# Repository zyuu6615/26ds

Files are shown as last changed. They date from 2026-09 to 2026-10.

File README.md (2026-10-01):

# 车载平衡滚球运动控制系统

> 2026 年全国大学生电子设计竞赛（TI 杯）赛区赛暨模拟电子系统设计专题赛选拔赛
> **H 题 · 省一等奖**

一辆四轮小车沿黑线循迹行驶，同时用一根舵机驱动的摆杆把钢珠稳定在指定位置。

```
MaixCAM2（NPU 视觉）──UART 115200──► STM32F407（控制）──► 舵机 / 双电机
     识别钢珠位置                     球杆闭环 + 循迹 + 显示
```

## 仓库结构

| 目录 | 内容 |
| :--- | :--- |
| [`01_firmware_stm32/`](01_firmware_stm32/) | 主控固件：循迹、双电机串级 PID、舵机、LCD、视觉串口 |
| [`02_vision_maixcam2/`](02_vision_maixcam2/) | MaixCAM2 视觉：NPU YOLO26 检测钢珠 + 多级容错跟踪 |
| [`03_mechanical_3d/`](03_mechanical_3d/) | 整车与摆杆机构 3D 模型（SolidWorks + 可打印 STEP） |
| [`04_dataset_tools/`](04_dataset_tools/) | 训练数据制作（视频抽帧）与标注格式说明 |

各模块的构建方式、参数含义与设计说明见各自的 README。

## 赛题任务

| 科目 | 要求 |
| :--- | :--- |
| 任务一 | 舵机在安全行程内往复摆动，车不动 |
| 任务二 | 从 A 点顺时针循线一圈停回 A 点，≤20s，停车偏差 ≤2cm |
| 任务三 | 车静止，把钢珠从中心 O 送到 +5cm 再折返 −5cm |
| 任务四 | 带球顺时针通过 B 点，≤8s |
| 任务五 | 球置中心 O，整圈通过 A，≤30s |
| 任务六 | 球置于摆杆任意指定位置并稳定在该位置附近 |

六科目全部实现。控制参数见 `01_firmware_stm32/applications/task.h`。

## 致谢

方案调研阶段参考了 H 题相关的开源实现
感谢运用到的第三方组件以及利用的其他开源方案，万分感谢！！
## 许可

原创代码以 MIT 协议开源，见 [LICENSE](LICENSE)。
`01_firmware_stm32/lcd_driver/` 内含第三方字模数据，版权归原作者；
SolidWorks 标准件参考模型仅供学习交流。

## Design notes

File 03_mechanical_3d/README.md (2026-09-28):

# 03 · 机械结构 3D 模型

车载平衡滚球小车的完整机械设计：底盘、车架、舵机支架、摆杆机构、视觉支架。
全部为自主建模

- **CAD**：SolidWorks（`*.SLDPRT` 零件 / `*.SLDASM` 装配体）
- **交换格式**：`printables_step/` 下 9 个 `*.STEP`，可直接切片打印

## 目录

```
26电赛.SLDASM              总装配体（从这个文件开始看）
*.SLDPRT                   18 个零件
printables_step/           9 个可打印 STEP
```

## 零件清单

### 结构件

| 文件 | 说明 |
| :--- | :--- |
| `大底盘.SLDPRT` | 主底盘，承载全部电子件与机构 ✅STEP |
| `下车架.SLDPRT` | 下层车架，承载电机与轮组 ✅STEP |
| `5CM架台.SLDPRT` | 抬高摆杆支点 ✅STEP |
| `视觉支架.SLDPRT` | 固定 MaixCAM2 ✅STEP |
| `挡板.SLDPRT` | 遮挡/限位 |

### 摆杆机构

| 文件 | 说明 |
| :--- | :--- |
| `水管.SLDPRT` | 摆杆（钢珠滚动导轨） |
| `摆杆撑杆.SLDPRT` | 摆杆撑杆 ✅STEP |
| `摆杆支撑转轴座.SLDPRT` | 转动支点 ✅STEP |
| `摆杆转轴侧固定座.SLDPRT` | 转轴侧向定位 |
| `舵盘摆臂杆.SLDPRT` | 舵机旋转 → 摆杆俯仰 ✅STEP |

### 舵机与连接件

| 文件 | 说明 |
| :--- | :--- |
| `舵机支架.SLDPRT` | 固定舵机本体 |
| `舵机固定脚.SLDPRT` | 舵机安装脚 ✅STEP |
| `连接件.SLDPRT` | 通用连接结构 ✅STEP |
| `合页.SLDPRT` / `合页2.SLDPRT` | 铰链结构 |
| `10kg高速舵机.SLDPRT` | 舵机参考体，非打印件 |
| `25T 塑料舵盘.SLDPRT` | 舵盘参考体，非打印件 |

> ✅STEP 表示该件在 `printables_step/` 下有对应导出。

## 机构要点

舵机旋转经 `舵盘摆臂杆` → `摆杆撑杆` 转成摆杆俯仰。舵机脉宽与倾角近似线性
（500–2500us 对应 0–180°），主控侧水平点标定值为 `1588us`。

撑杆高度会放大同样的舵机转动量对应的倾角变化，等效于改变整个位置环的增益，
**换机构必须重新整定 PID**。

视觉支架的安装角度需保证摆杆在画面中接近水平，否则 `AXIS_*_PX` 要重新标定。

## 使用

1. **看装配**：SolidWorks 打开 `26电赛.SLDASM`，若提示找不到零件，
   把所有文件放同一目录再打开。
2. **直接打印**：用 `printables_step/` 里的 STEP 导入切片软件即可，
   无需 SolidWorks（Fusion / FreeCAD / PrusaSlicer 都能读）。

> 打印参数（层高、填充率、材料、支撑）当时未记录。一般建议承力件用较高填充率，
> 转轴座与撑杆的配合面注意层纹方向以获得更好的抗弯强度。

## 注意

`10kg高速舵机.SLDPRT` 与 `25T 塑料舵盘.SLDPRT` 是外购标准件的参考模型，
用于装配干涉检查，不是打印件，版权归原厂商。

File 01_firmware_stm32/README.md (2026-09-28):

# 01 · STM32F407 主控固件

平衡滚球系统的主控。负责循迹、双电机闭环、舵机摆杆控制、LCD 显示，
以及接收 MaixCAM2 的钢珠坐标并做球杆闭环。

- **MCU**：STM32F407ZGT6
- **构建**：CMake ≥ 3.22 + Ninja + `arm-none-eabi-gcc`
- **调试**：OpenOCD + Cortex-Debug

## 目录

```
applications/          应用层，业务代码都在这里
  app.c/.h             调度入口：10ms 内环 / 20ms 外环 / 显示
  task.c/.h            六个赛题科目的状态机与参数
  tracking.c/.h        循迹外环：灰度质心 -> 转向 PID -> 差速
  pid.c/.h             位置式 PID（微分先行 + 积分限幅）
  motor.c/.h           TB6612FNG 双路电机驱动
  encoder.c/.h         TIM1/TIM3 正交编码器，软件补 16->32 位回绕
  grayscale.c/.h       I2C 8 路灰度传感器
  servo.c/.h           舵机 PWM 驱动 + 往复自检演示
  vision.c/.h          UART4 视觉协议接收
  ball.c/.h            钢球位置环 PD + 加速度前馈
  key.c/.h             4 路按键消抖与边沿检测
  ball_notes.md        球杆闭环调参实测记录
Core/                  CubeMX 生成的 HAL 初始化与中断
Drivers/               CMSIS + STM32F4xx HAL（ST 官方，未改动）
cmake/                 工具链文件与源码列表
lcd_driver/            SPI LCD 驱动 + GB2312 全字库（见下方编码说明）
tools/gen_gb2312_font.py   字库生成脚本
openocd.cfg            下载器配置
STM32F407XX_FLASH.ld   链接脚本
```

## 调度层次

| 周期 | 任务 |
| :--- | :--- |
| 10ms | `Key_Scan()`、速度内环（编码器 → 速度 PID → PWM） |
| 20ms | `Track_Update()` 循迹外环、`Task_Update()` 任务调度、`Ball_Update()` 球杆闭环 |

内环周期必须快于外环，两者由 `APP_OUTER_EVERY` 关联，改一处不会漏另一处。

## 引脚分配

| 功能 | 引脚 | 复用 |
| :--- | :--- | :--- |
| 左/右电机 PWM | PC6 / PC7 | TIM8_CH1 / CH2（20kHz） |
| 左/右电机方向 | PF0/PF1、PF2/PF3 | GPIO |
| 驱动使能 STBY | PF4 | GPIO |
| 左编码器 | PB4 / PA7 | TIM3_CH1 / CH2（AF2） |
| 右编码器 | PE9 / PE11 | TIM1_CH1 / CH2（AF1） |
| 灰度传感器 | PB8 / PB9 | I2C1（地址 0x4C） |
| 舵机 | PD15 | TIM4_CH4（50Hz，500–2500us） |
| 视觉串口 | PA0 / PA1 | UART4（115200 8N1） |
| 按键 | PC2 / PC0 / PF9 / PF7 | KEY1–KEY4 |

## 视觉协议

```
$BALL,<valid>,<x_cm>,<vx_pixel_s>,<confidence>,<frame_time_ms>[,<touch_cm>]*\n
```

`vision.c` 用 UART4 中断 + 512B 环形缓冲接收，单帧上限 64B，
超过 `VISION_TIMEOUT_MS`(200ms) 无有效帧则判定断链。

## 构建

```bash
cmake --preset Debug
cmake --build --preset Debug
```

或用 VS Code 任务 `OpenOCD: flash`。依赖 `arm-none-eabi-gcc`、CMake ≥ 3.22、Ninja、OpenOCD。

`CMakeLists.txt` 里的 `-u _printf_float` 不可删除，`LCD_DisplayDecimals()` 依赖它。

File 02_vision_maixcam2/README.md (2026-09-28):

# 02 · MaixCAM2 视觉模块

平衡滚球系统的视觉前端。在 MaixCAM2 上用 NPU 检测钢珠，换算成摆杆轴线上的
厘米位置，通过串口发给 STM32 主控。

**只负责识别与上报，不参与运动控制。**

- **平台**：MaixCAM2（AX 系列 SoC，带 NPU）
- **框架**：MaixPy
- **模型**：YOLO26 单类检测（`ball`），640×160 输入
- **通信**：UART `/dev/ttyS4` @ 115200 8N1

## 文件

| 文件 | 作用 |
| :--- | :--- |
| [`main.py`](main.py) | 主程序：采集、推理、轴线标定、触摸交互、串口上报、屏幕叠加 |
| [`hybrid_tracker.py`](hybrid_tracker.py) | `HybridBallTracker` —— 多级容错跟踪 |
| [`ball_position.py`](ball_position.py) | 像素 → 物理量换算与自适应 α-β 滤波 |
| [`app.yaml`](app.yaml) | MaixPy 应用打包描述 |
| `models/` | 模型描述文件（`*.mud`）。权重 `*.axmodel` 未入库 |

代码本身注释极简，阈值与标定值都维护在本文档的参数表里。

## 处理流程

```
相机帧 → NPU YOLO26 → 候选筛选 → [丢失时] 多级降级跟踪
                                        │
        像素坐标 → 正交投影到标定轴 → 比例 → cm
                                        │
        自适应 α-β 滤波 → 串口 $BALL → STM32
```

正常帧只跑 YOLO。丢框时按代价从低到高降级：
局部模板匹配 → CLAHE 亮度增强后重检 → 低频全画面模板重定位。
未采用全图 Hough 与 FFT，边缘算力不足。

### 滤波（`ball_position.py`）

| 参数 | 值 |
| :--- | :--- |
| α（静止 → 快动） | `0.20 → 0.95` |
| β | `0.01 → 0.12` |
| `dt` 钳位 | `[5ms, 100ms]` |
| 重置超时 | `250ms` |
| 速度平滑 | `0.65 / 0.35` |

## 串口协议

```
$BALL,<valid>,<x_cm>,<vx_pixel_s>,<confidence>,<frame_time_ms>[,<touch_cm>]*\n
```

`frame_time_ms` 是视觉模块自己的时间戳，只能用于判断视觉端是否卡帧，
不可与 STM32 的 `HAL_GetTick()` 做差。`touch_cm` 是触摸屏指定的目标位置。
主控侧解析见 [`../01_firmware_stm32/applications/vision.c`](../01_firmware_stm32/applications/vision.c)。

## 模型权重

`models/` 下只保留了可读的 `.mud` 描述文件，权重 `*.axmodel`（约 2.6MB/个）未入库。

自行复现：用 [`../04_dataset_tools/`](../04_dataset_tools/) 抽帧 → 标注单类 `ball`
→ 训练 YOLO26 → 转成 AX 系列 NPU 格式 → 连同 `.mud` 放进 `models/<name>/`
→ 更新 `main.py` 里的 `MODEL_PATH`，**并重新标定 `AXIS_*` 四个值**。

## 运行

把 3 个 `.py`、`app.yaml` 与 `models/` 一起按 MaixPy 应用打包后推送到设备。
调试开关都在 `main.py` 顶部（`DEBUG_LOG` / `DRAW_DEBUG` / `SHOW_FPS` /
`USE_WEBRTC` / `PRINT_PROTOCOL` / `TOUCH_*` / `LENS_CORR_*`）。

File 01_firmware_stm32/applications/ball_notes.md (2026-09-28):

# 球杆闭环 —— 实测记录与踩过的坑

重写 `ball.c` / `ball.h` 前把旧版本里【实测得来、不能靠推导重新得到】的信息
留在这里。旧的完整实现（含增益调度、静摩擦补偿、摩擦前馈等全套机制）在
git 提交 `42467a3` 及之前，需要时可以取回。

> ## ⚠ 关于历史参数的一条前提
>
> `b418f9d`（提交信息"快速稳定定点"，Kp=45 / Ki=5 / Kd=68 / 限幅 500 / 全机制开）
> 跑在 **`SERVO_LEVEL_US = 1640`** 上。`42467a3`（"失败"）水平点**仍是 1640**，
> 只是把增益退了回来。**1757 是在那之后才改出来的**，只在纯 PD 的反推实验里
> 验证过左右对称性，从来没有跑过一个真正收敛的闭环。
>
> 所以 **b418f9d 那套参数不能直接抄到 1757 上**：1640 偏了约 117us，它的静摩擦
> 补偿（预载 100 / 天花板 320）有相当一部分实际是在补这个水平点偏差，
> 换到 1757 之后整套配比都不再成立。

## 当前进度

- **阶段一 · 纯 PD** —— 已实现（`ball.c` 控制律段）。Kp=25 / Ki=0 / Kd=45 / 限幅 300，
  其余机制全部未加回。**验收标准：球不来回摆。** 停在离目标一段距离处不动是
  预期结果，不是故障。
  - 第一次实测：**不振荡（阻尼够，Kd 不用动）**，但两个停止点是 17.5 和 20~22，
    **全在目标同一侧** → 水平点偏高约 169us，目标点根本不是平衡点。
  - 处理：`SERVO_LEVEL_US` 1757 → **1588**（推导见 servo.h 第四轮）。待复测。
- 阶段二及以后：见第五节。

> ### 一条新学到的判据
>
> **两个停止点落在目标的同一侧 = 水平点偏了，且偏移量大于起步门槛。**
> 一正一负把目标夹在中间，才说明只剩噪声、可以停止迭代。
> 前三轮之所以误判"已经在噪声里打转"，就是因为当时确实是夹住的 ——
> 方法没错，错在把一次姿态下的结果当成了常数。**姿态一变就得重跑这三行。**

---

## 一、对象模型

球在管子上滚，摆杆倾角决定的是球的**加速度**而不是位置：

```
x'' = (5/7) * g * sin(theta)
```

也就是一个**双积分器**，本身零阻尼、临界稳定。由此得到两条结论，重写时仍然成立：

1. **纯 P 一定等幅振荡。** 比例项只提供"回中的力"，提供不了"刹车的力"。
   D 项不是可选项，是稳定的必要条件。
2. **杆放平不等于球会停**，只是不再加速。要让运动的球停下来，必须先把杆往
   **反方向**倾斜给它减速。

---

## 二、实测基线数据

| 量 | 实测值 | 怎么来的 |
|---|---|---|
| 目标位置（摆杆中心 O） | 12.5 cm | 直接量 |
| 舵机水平点 `SERVO_LEVEL_US` | 1757 us | 闭环反推，三轮迭代，详见 servo.h |
| 机构安全行程 | 1050 ~ 2400 us | 见 servo.h，**这是唯一的保护手段** |
| 相对水平点的可用对称行程 | ±620 us | 向下 1757-1050=707，向上 2400-1757=643，取小 |
| 静摩擦起步门槛 T | ≈ 72 ~ 90 us | 闭环反推（见下）。**不是**早期手动扫描量到的 160/520 |
| 视觉位置噪声 | ≈ 0.1 cm | 球静止时的读数抖动 |
| 视觉速度噪声（差分后） | ≈ 1.3 cm/s | 0.1cm / 30fps 差分，视觉端已做滤波 |
| 视觉总延迟 | ≈ 75 ~ 100 ms | 30fps 采样 + 视觉端滤波（**不含**本地速度低通，见下） |
| 帧率 | 30 fps（dt ≈ 33 ms） | — |

> **勘误（重写时查代码发现）**：本地的 `BALL_VEL_LPF` **从来没有进过微分通路**。
> `pid.c:91` 的 D 项是模块自己从位置做**原始差分**算的，旧 `ball.c` 一直调用
> `PID_Update(&s_pid, s_target_cm, s_pos_cm)`，那个低通过的 `s_vel_cm_s` 只喂给了
> 静摩擦判据和摩擦前馈。旧 ball.h 里"它同时喂给微分项和静摩擦判据"那句是错的。
>
> 两个后果：
> 1. D 项的实际噪声是 `Kd × 3 cm/s`（不是 `Kd × 1.3`）。Kd=68 时约 **204us**，
>    远超起步门槛 —— 舵机自己就在推球，这多半是当初"越调越乱"的一个隐藏原因。
> 2. 反过来说，D 通路的滞后**比笔记原先记的小**，只有采样延迟。所以
>    "要不要把滤波后的速度接进 D 项"是一笔真实的取舍，不是显然的改进：
>    接进去能压噪声，但要多付约 77ms（= dt × (1-α)/α）的滞后，
>    而这个对象的稳定性正卡在延迟上。**要改就单独改一次，别和别的动作混在一起。**

### 起步门槛 T 是怎么测的

**不要用手动扫描。** 主界面 US 字段是轮流刷新的（约 280ms 一轮），按住连发时
读数滞后几十 us，而这个滞后只要在一个方向上更严重，量出来的中点就被拽偏。
早期量到 T=160us（甚至 520us）全是这么虚高出来的，并且直接导致了后面所有
参数集体超标。

**用闭环反推，没有人工判读环节：** 跑纯 PD（Ki=0，Kp=25），把球从两侧拨开松手，
记下它停住的位置。球静止时 D 项为 0，此时舵机倾角 = `Kp × 偏差`，而它恰好就是
"推不动球的最大倾角"。多点联立得到静止带的宽度和中心：

```
从 17.5 回来停在 14.2  ->  静止倾角 25 × (-1.7) = -42.5 us
从 7.5  回来停在 8.4   ->  静止倾角 25 × (+4.1) = +102.5 us
```

两个倾角都推不动球 → 静止带至少覆盖 [-42.5, +102.5]，宽度 145us → **T ≥ 72us**。
带中心偏离 0 的量就是水平点的残余误差（这一步用来迭代 `SERVO_LEVEL_US`）。

**迭代到 1757 就该停。** 再往下抠是拿噪声当信号：残余偏差（约 22us）已经小于
起步门槛 T，球停在静止带里的哪一点本身就有 ±T 的自由度。剩下的不对称还有
一部分根本不是水平点造成的（两侧回中行程不等造成的动量差、管子局部摩擦差异），
不是一个全局常数修得掉的。

> **车身姿态一变就要重测。** 起步门槛只有几十 us，而姿态每偏 1 度水平点就挪
> 80~160 us —— 换个地面、换块垫子都足以让球停不住。

---

## 三、带宽的硬上限：视觉延迟

这是最贵的一条教训。

一路提速 Kp（35 → 50 → 60 → 100，限幅 350 → 500）之后，在 12.5 处出现
**OUT 峰值 450us、正负翻转**的振荡。这不是静摩擦极限环（当时前馈最多给 85us、
补偿天花板 320us，都到不了 450），是 PID 自己在两侧限幅之间来回撞，即闭环失稳。

根因是视觉延迟约 75~100ms。延迟给闭环带宽划了一条硬上限：闭环自然频率
`wn = sqrt(K × Kp)`，相位裕度大致按 `wn × tau` 被吃掉。越过这条线之后：

> **加 Kd 不再有用，反而更糟。** 因为微分是从**同一路延迟信号**算出来的，
> 它补的是"球刚才的速度"，相当于又叠了一份滞后。"Kd 正比 sqrt(Kp) 以保持
> 阻尼比"这条规律只在无延迟的线性模型里成立，过了延迟极限就失效。

**想真正提高带宽，出路不在增益，而在减小延迟**：提高视觉帧率、减小视觉端和
本地速度低通的滤波强度。延迟减半，可用的 Kp 才能翻倍。

同理，**限幅不是越大越好**：限幅高会让饱和更深，而饱和本身就是失稳源 ——
饱和期间 Kp/Kd 的比例关系完全失效，控制器退化成 bang-bang（全程满舵加速，
等该刹车时已经晚了）。上一版最后是退回 Kp≈25 / Kd≈45 / 限幅 300 才稳住的。

---

## 四、旧实现里叠的机制，以及它们各自的坑

旧版本同时开着七八个会互相作用的机制，任何一个出问题都表现成"球在振荡"，
同时开着**根本无法归因** —— 上一轮就是这么陷进去的。这些机制本身的道理是对的，
坑在于取值和叠加方式。

### 1. 静摩擦补偿（球停住时逐步加大倾角直到起步）

- **要解决的现象**：用力拨开能归位，轻轻拨 2~3cm 却纹丝不动。用力拨时球全程
  带速度，只需克服动摩擦；轻轻拨时球静止，小偏差算出的小倾角够不着起步门槛。
- **撤销判据要用位置不要用速度**：位置噪声只有 0.1cm，速度是差分出来的、噪声
  1.3cm/s 还被低通滤了几十 ms —— 等速度反应过来时球已经带着大倾角猛加速了那么久，
  必然冲过目标。
- **天花板宁大勿小**：给大了没代价（球一动就撤销，容易起步的位置根本爬不到）；
  给小了会**死锁** —— 球停在离目标 1~2cm 处不动，OUT 读数钉死在那个值上。
- **预载宁小勿大**：预载必须低于管子上**最容易**起步那一处的门槛，超了就是
  一武装就把球踢飞。**注意天花板和预载的取值方向相反**（天花板取最难起步处、
  预载取最容易起步处），旧版本一度把预载写成天花板的比例，必然打架。
- **棘轮陷阱**：只用"速度够低"一条判据武装的话，球挪完撤销距离后速度通常只有
  2~3cm/s，仍低于门槛 → 立刻重新武装、又加载一次预载，反复下来等于全程踩着
  油门把球一路推过目标，表现为**在目标两侧来回摆荡**。必须再加一条方向判据：
  球已经在朝目标滑就收手。
- **死区是最后一道闸**：折返点速度本来就接近 0，仍满足武装条件，还是会挨一脚。
  只有"偏差小于某值就彻底撒手"才能真正断掉摆荡。任务要求是误差 ≤1cm 而不是 0，
  稳稳停在死区边上是合格的，在 0 附近摆荡反而随时可能超标。

### 2. 摩擦前馈（在输出上直接加一个常量抵消库仑摩擦）

- **安全性质**：前馈量必须**低于**实测起步门槛，保证前馈单独推不动静止的球，
  最后那一下必须由比例项提供。这样即便符号写反或视觉数据过期，最坏情况也只是
  球停着不动，不会出现"球自己越跑越远"的失控。旧版本把它填到 130/85us 而真实
  门槛只有约 90us —— **超标了**，这是那轮振荡的帮凶之一。
- **球跑起来必须淡出**：动摩擦比静摩擦小，球在动时 D 项已经主导，再叠同向推力
  等于跟刹车对着干；球冲过目标往回滚时 err 已反号，此时前馈与摩擦同向，变成
  双份制动会把球顶回去。

### 3. 增益调度（偏差大用激进参数，进细调区换温和参数）

限幅**不要**跟着调度走，始终保持最大 —— 它同时管着"加速"和"刹车"两个方向，
球高速冲进细调区时刹车权限突然缩水会更容易冲过头。

### 4. 积分项

唯一能把稳态误差消到 0 的手段，但在这个对象上代价大：静摩擦系统特有的
**粘滑振荡**（积分憋到球突然挣脱、冲过头、再反向憋），且积分是纯滞后项，
而双积分器对象相位裕度本来就紧。

**不要拿积分当静摩擦补偿用**（旧版本 Ki=25 就是让积分自己爬到 520us 去顶开
静摩擦），那只会加剧过冲。更干净的做法是直接微调 `SERVO_LEVEL_US`，
积分最多只负责吃掉水平点几十 us 的残余标定误差。最后一版索性 Ki=0。

### 5. 速度低通

系数越小滤得越狠但滞后越大。微分项对滞后极敏感，旧版最终取 0.30
（滞后约 75ms）。注意 Kd × 速度噪声就是输出的抖动幅度，只要它明显低于起步门槛，
球感觉不到，舵机的轻微抖动反而起 **dither** 作用，有助于把静摩擦线性化；
一旦抖动幅度越过起步门槛，舵机自己就把球推走了 —— **那才是 Kd 真正的天花板**，
不是"看着不舒服"。

### 6. 加速度前馈（小车起步时）

小车起步加速，球因惯性相对摆杆向后滑。反馈对此无能为力（只能在球已经被拽出去
之后才开始修），但小车的加速度是我们自己下达的指令，完全已知，所以应该前馈。
**这一路实测有效，保持开启。**

标定：跑任务四，看起步瞬间球的最大位移 —— 还往后滑就加大，反而往前冲就减小。

### 7. 过弯前馈（v × 轮速差）

**实测关闭，开启后过弯反而变差。** 入弯时被前馈推偏，出弯时轮速差骤降、前馈
随之撤销，球被留在偏离位置上还带着速度，表现为"出弯时球会跑"。

根子在于这条前馈只补偿了**稳态**向心加速度 v×omega，而出入弯真正伤球的是
omega 的**变化率**。而实测表明纯反馈已经能应付过弯（球本来就不怎么动），
没必要引入这份额外扰动。

---

## 五、重写时的整定顺序

### 第 0 步：确认符号（做错后面全白搭）

Kp/Ki/Kd 全设为 0 再使能闭环 —— 此时输出恒为 0、杆保持水平，舵机不会动，是安全的。
然后只把 Kp 设成很小的值（比如 2），用手把球放在大于 12.5cm 的一侧，看杆往哪边倾：

- 杆倾斜的方向让球**滚回中心** → 符号对
- 球被推得更远 → 把 `BALL_OUTPUT_SIGN` 改成 -1

符号错了就是正反馈，球会瞬间冲到杆的一端，**别在高增益下试这一步**。

### 第 1 步：先加 Kd，不是先加 Kp

这和电机速度环的习惯相反。双积分器没有任何自然阻尼，Kp 单独作用时系统临界稳定，
球会绕着中点等幅振荡，这时候再怎么调 Kp 都没用。

保持 Kp 很小，把 Kd 从 5 开始往上加。**验收**：用手把球推开 5cm 后松手，
球回中的过程最多过冲一次就停住，不来回摆。

### 第 2 步：再调 Kp

Kd 够了之后 Kp 决定回中的快慢。太小则球慢吞吞往回挪或停在偏离处不动；
太大又开始振荡（此时继续加 Kd，两者配套往上走）。

**上限判据有两条**：① 常用偏差 × Kp 不能打满限幅（否则退化成 bang-bang）；
② 到了第三节说的延迟极限之后加 Kd 也压不住，那就是真的到顶了，别再硬提。

> **纯 PD 阶段球必然停在离目标一段距离处不动，这是正常的**，不是故障 ——
> 纯 PD 顶不过静摩擦。那段距离正是静摩擦补偿的输入（停止距离 × Kp ≈ 门槛 T）。

### 第 3 步及以后：一次只加一个机制

上一轮的教训就是同时开着一堆机制没法归因。**每加一个机制只调一个数，
上一阶段验收通过才进下一阶段。**

---

## 六、不变量（重写后仍必须满足）

1. **视觉断链必须回平**，不能保持上一次的输出 —— 斜着的杆会让球一直加速，
   几百毫秒就冲出去了。放平至少让它匀速滑行。
2. **只在收到新帧时跑控制**。按固定周期跑的话，两帧之间位置没变，微分项会在
   "没变"的拍上读到 0、在"变了"的拍上读到尖峰，等于给控制器喂一串噪声。
3. **dt 必须夹在合理范围内**。视觉端卡顿或刚上电时 dt 异常，不夹住微分项会算出
   天文数字，舵机瞬间打死。
4. **速度自己按 x_cm 差分**，不要直接用视觉发来的 `vx_pixel_s` —— 后者单位是
   像素/秒，与 cm 的比例和正负方向都取决于摄像头安装，用错方向的微分等于把
   阻尼变成正反馈。等标定出比例和符号之后再换成它会更平滑（源头是滤波器输出）。
5. **重新使能时清空历史**，否则会带着上一轮的积分猛推一下。
6. **所有下发脉宽都要过 `Servo_SetPulseUs()`**，它内部夹在 `SERVO_SAFE_*` 里。
   舵机没有任何反馈回单片机，读不到位置也读不到堵转电流 ——
   **绝不发出越界的指令是唯一可行的保护**。

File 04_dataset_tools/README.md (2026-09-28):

# 04 · 训练数据工具

为 [`../02_vision_maixcam2/`](../02_vision_maixcam2/) 的 YOLO26 钢珠检测模型准备训练数据。

**本仓库只含脚本，不含图片数据** —— 标注帧与视频约 90MB，请用下面的脚本自行生成。

## 文件

| 文件 | 作用 |
| :--- | :--- |
| [`video_to_frames.py`](video_to_frames.py) | 把视频按固定间隔抽帧保存为图片（OpenCV） |

## 用法

```bash
# 每帧都保存
python video_to_frames.py raw/2.mp4

# 指定输出目录、每 5 帧存一张、png 格式
python video_to_frames.py raw/2.mp4 -o ./2_frames -i 5 -f png

# 缩放到 640x480
python video_to_frames.py raw/2.mp4 --size 640 480
```

| 参数 | 默认 | 说明 |
| :--- | :--- | :--- |
| `video` | — | 输入视频路径 |
| `-o, --output` | 视频同目录 `<名字>_frames/` | 输出目录 |
| `-i, --interval` | `1` | 每多少帧保存一张 |
| `-f, --format` | `jpg` | `jpg` / `jpeg` / `png` |
| `--size W H` | 保持原分辨率 | 输出分辨率，宽高须同时给出 |

> ⚠ 输出的 `frame_%06d` 是**保存序号**，不是原视频帧号。`-i > 1` 时两者不同，
> 需要回溯具体时刻请自行乘上 `interval`。

## 标注格式

每张图配一个同名 `.json`，为 X-AnyLabeling / Labelme 兼容格式：

```json
{
  "version": "4.0.0-beta.13",
  "flags": {},
  "shapes": [],
  "imagePath": "frame_000400.jpg",
  "imageHeight": 480,
  "imageWidth": 640,
  "imageData": null,
  "description": ""
}
```

有目标时 `shapes` 里是 `{"label": "ball", ...}`；**空 `shapes` 是刻意保留的负样本**，
用于压制反光点等圆形干扰物的误检，不要删除。

## 完整流程

1. **采集**：实地拍摄钢珠在摆杆上滚动的视频，覆盖不同光照、背景、钢珠位置与运动模糊。
2. **抽帧**：`video_to_frames.py`，间隔取 `2` 左右通常够用。
3. **标注**：X-AnyLabeling 单类 `ball`，**务必包含足够的负样本帧**。
4. **训练**：YOLO26 单类训练，可降低输入分辨率换取 NPU 帧率。
5. **转换**：导出 AX 系列 NPU 的 `.axmodel`。
6. **部署**：放进 `02_vision_maixcam2/models/<name>/`，更新 `main.py` 的 `MODEL_PATH`，
   **并重新标定 `AXIS_START_PX` / `AXIS_END_PX` / `AXIS_START_CM` / `AXIS_END_CM`**。

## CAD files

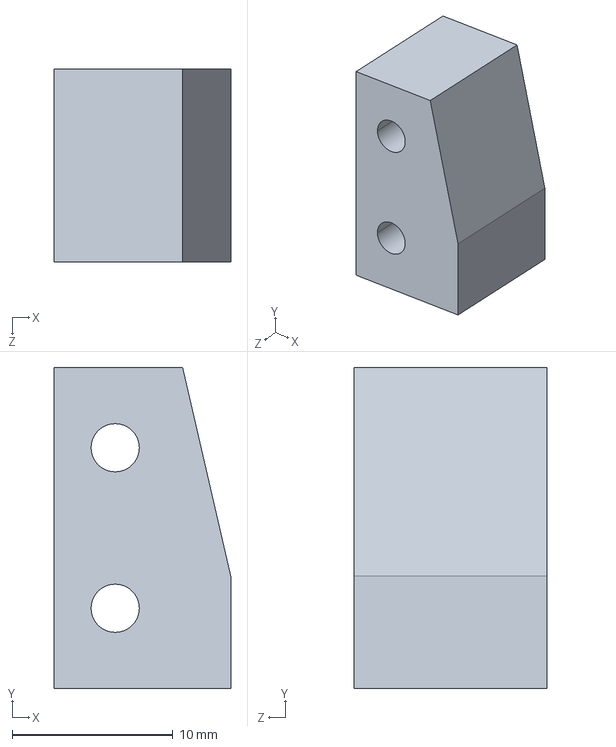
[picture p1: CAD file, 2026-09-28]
03_mechanical_3d/printables_step/舵机固定脚.STEP
11.0 x 20.0 x 12.0 mm

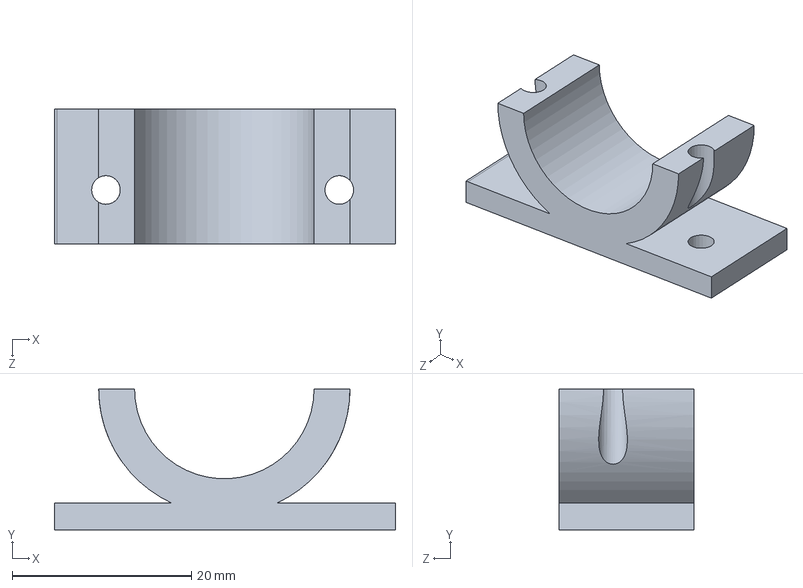
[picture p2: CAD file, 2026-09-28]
03_mechanical_3d/连接件.SLDPRT
38.0 x 15.7 x 15.0 mm

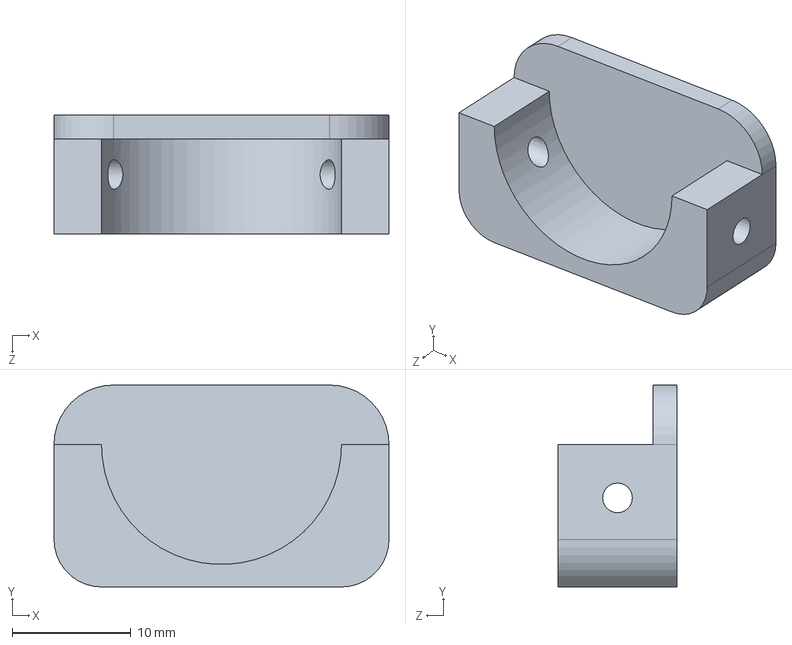
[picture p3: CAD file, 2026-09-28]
03_mechanical_3d/摆杆转轴侧固定座.SLDPRT
28.2 x 17.0 x 10.0 mm

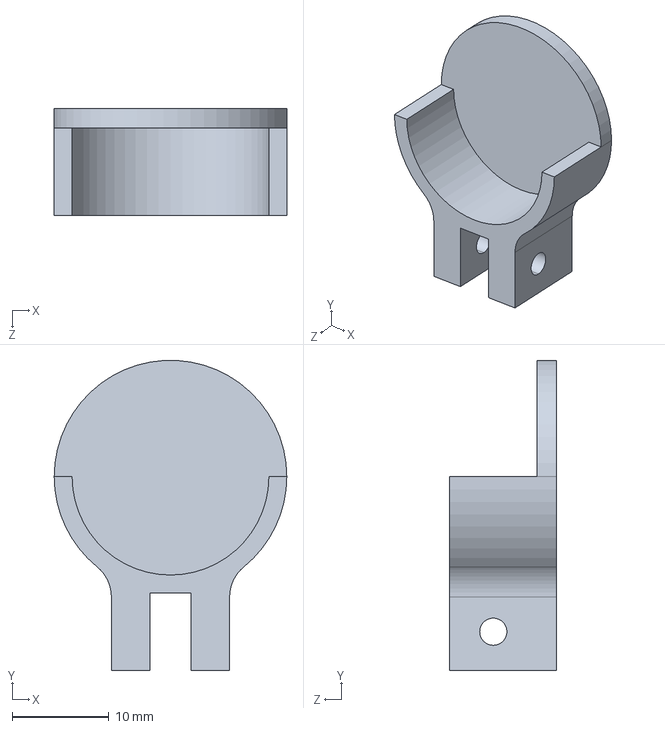
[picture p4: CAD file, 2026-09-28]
03_mechanical_3d/printables_step/摆杆支撑转轴座.STEP
24.0 x 32.0 x 11.0 mm

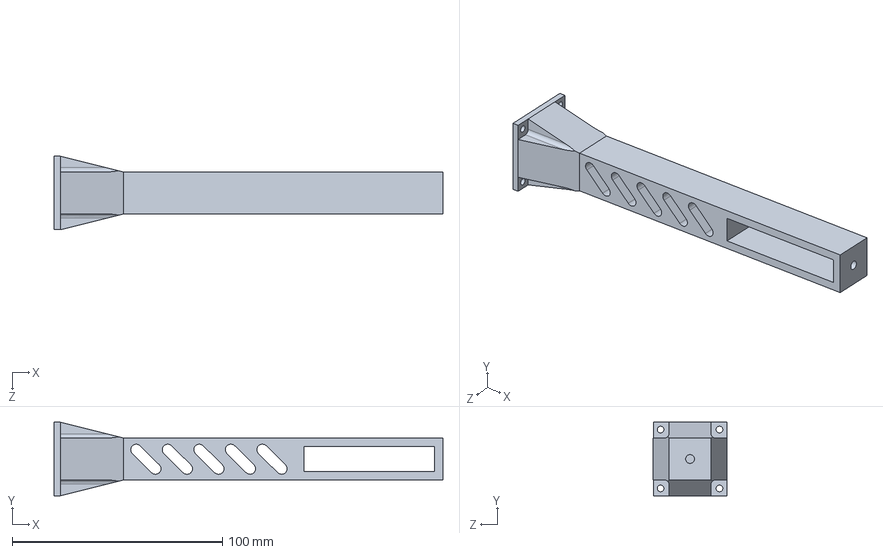
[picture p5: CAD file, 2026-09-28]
03_mechanical_3d/视觉支架.SLDPRT
185.0 x 35.0 x 35.1 mm

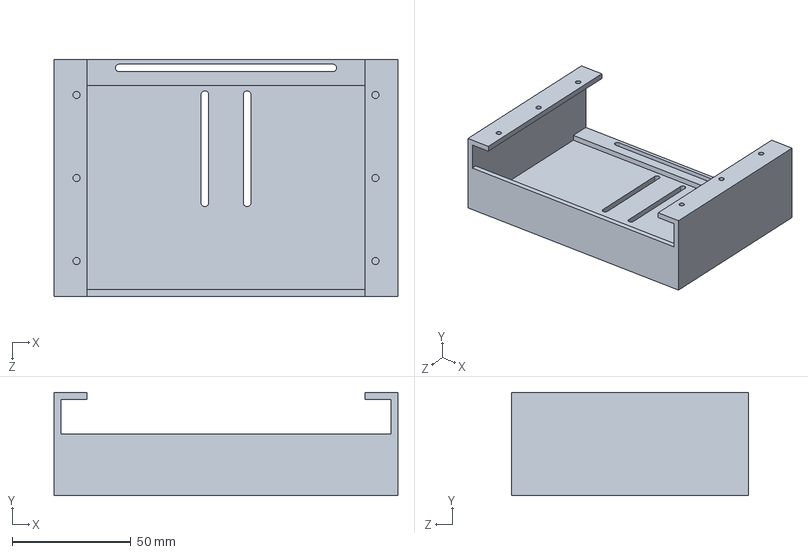
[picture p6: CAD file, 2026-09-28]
03_mechanical_3d/printables_step/下车架.STEP
145.0 x 43.5 x 100.0 mm

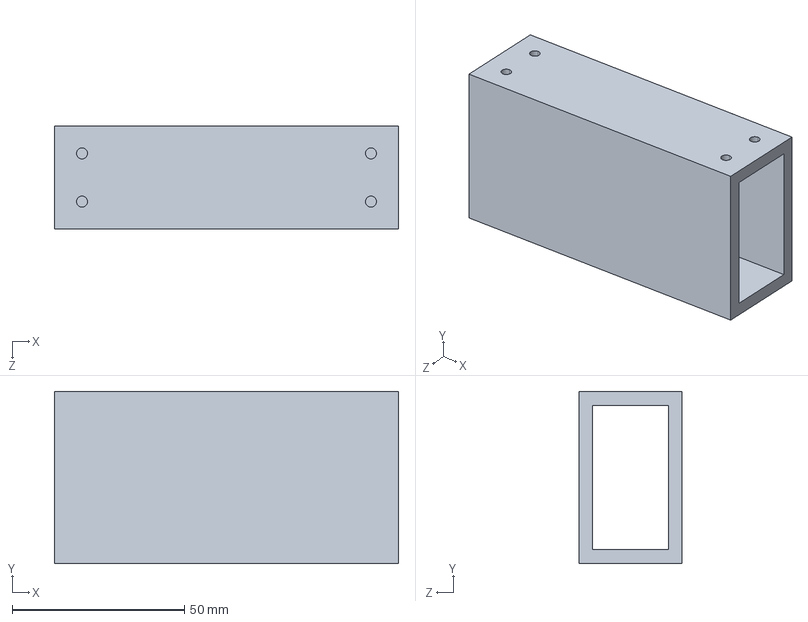
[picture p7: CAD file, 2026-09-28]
03_mechanical_3d/printables_step/5CM架台.STEP
100.0 x 50.0 x 30.0 mm

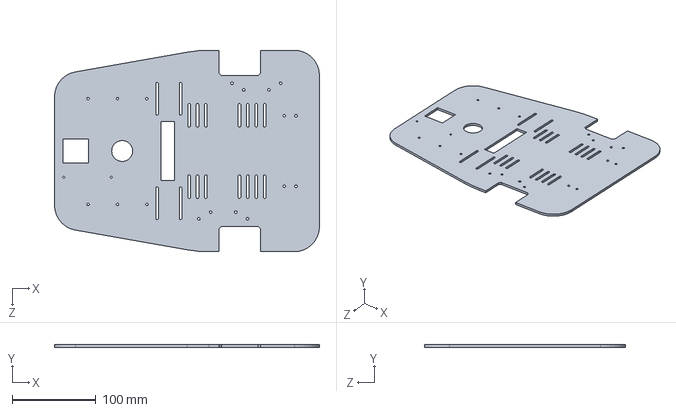
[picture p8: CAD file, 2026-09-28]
03_mechanical_3d/大底盘.SLDPRT
315.7 x 3.00 x 240.0 mm

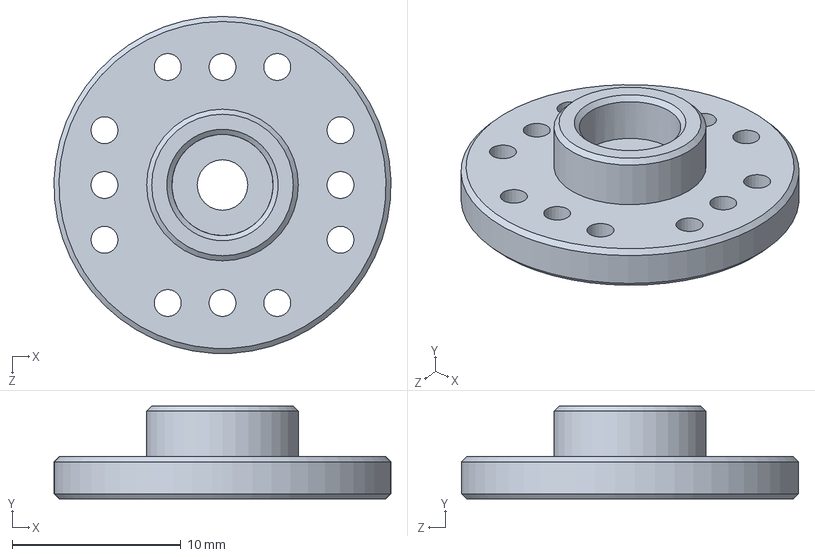
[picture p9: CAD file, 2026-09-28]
03_mechanical_3d/25T 塑料舵盘.SLDPRT
20.0 x 5.50 x 20.0 mm

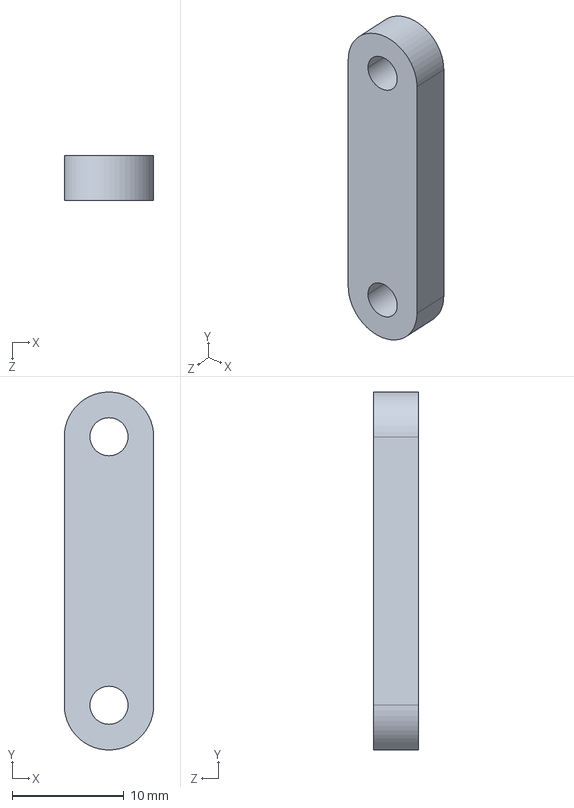
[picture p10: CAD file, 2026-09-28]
03_mechanical_3d/printables_step/摆杆撑杆.STEP
8.00 x 32.0 x 4.00 mm

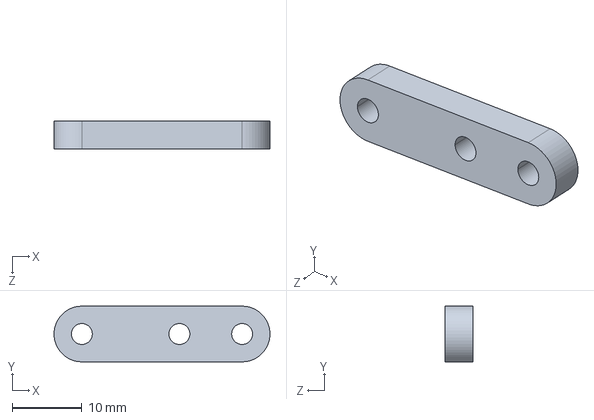
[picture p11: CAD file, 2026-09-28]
03_mechanical_3d/printables_step/舵盘摆臂杆.STEP
31.0 x 8.00 x 4.00 mm

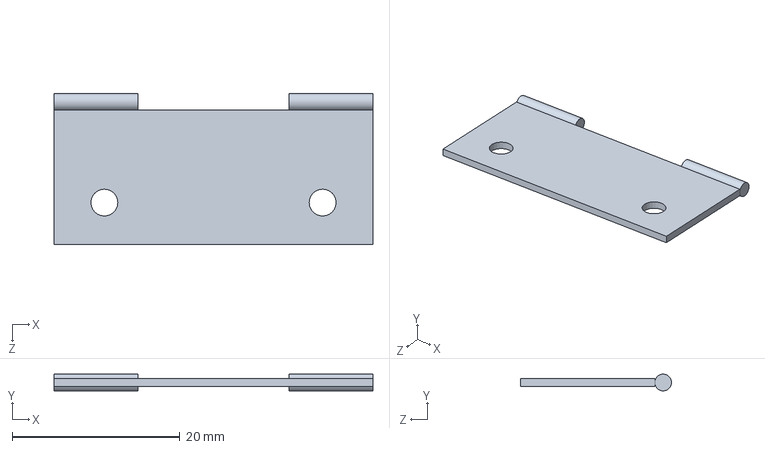
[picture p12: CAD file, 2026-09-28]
03_mechanical_3d/合页.SLDPRT
38.0 x 2.00 x 18.0 mm

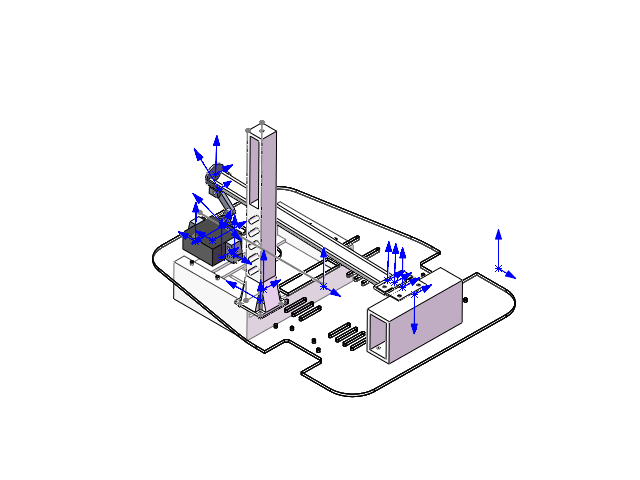
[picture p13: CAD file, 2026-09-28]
03_mechanical_3d/26电赛.SLDASM
大底盘
5CM架台
视觉支架
下车架
零件1
舵机固定脚 x 2
摆杆撑杆
25T 塑料舵盘
摆杆支撑转轴座
舵盘摆臂杆
连接件
水管
10kg高速舵机
合页
合页2

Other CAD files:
03_mechanical_3d/printables_step/连接件.STEP
03_mechanical_3d/摆杆支撑转轴座.SLDPRT
03_mechanical_3d/printables_step/视觉支架.STEP
03_mechanical_3d/printables_step/大底盘.STEP
03_mechanical_3d/下车架.SLDPRT
03_mechanical_3d/10kg高速舵机.SLDPRT
03_mechanical_3d/5CM架台.SLDPRT
03_mechanical_3d/合页2.SLDPRT
03_mechanical_3d/挡板.SLDPRT
03_mechanical_3d/摆杆撑杆.SLDPRT
03_mechanical_3d/水管.SLDPRT
03_mechanical_3d/舵机固定脚.SLDPRT
03_mechanical_3d/舵机支架.SLDPRT
03_mechanical_3d/舵盘摆臂杆.SLDPRT

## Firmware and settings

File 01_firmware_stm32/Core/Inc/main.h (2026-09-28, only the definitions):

#define key4_Pin GPIO_PIN_7
#define key4_GPIO_Port GPIOF
#define key3_Pin GPIO_PIN_9
#define key3_GPIO_Port GPIOF
#define key2_Pin GPIO_PIN_0
#define key2_GPIO_Port GPIOC
#define key1_Pin GPIO_PIN_2
#define key1_GPIO_Port GPIOC

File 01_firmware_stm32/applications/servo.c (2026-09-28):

/* ================= 舵机驱动 =================
   180 度舵机  TIM4_CH4 / PD15
   复用由 MX_TIM4_Init() 完成，须在其之后调用                    */

#include "servo.h"
#include "tim.h"

#define SERVO_TIM_HANDLE    (&htim4)
#define SERVO_TIM_CHANNEL   TIM_CHANNEL_4

/* 每度对应多少微秒 */
#define SERVO_US_PER_DEG    ((float)(SERVO_MAX_PULSE_US - SERVO_MIN_PULSE_US) \
                             / SERVO_MAX_ANGLE_DEG)

/* ---------------- 运行时状态 ---------------- */
static float    s_angle_deg = 0.0f;
static uint16_t s_pulse_us  = SERVO_SAFE_MIN_US;
static uint8_t  s_at_limit  = 0;    /* 上次设定是否被安全限位截断 */

/* 演示用 */
typedef enum
{
  SERVO_DEMO_HOLD_MIN = 0,
  SERVO_DEMO_SWEEP_UP,
  SERVO_DEMO_HOLD_MAX,
  SERVO_DEMO_SWEEP_DOWN
} Servo_DemoState;

static Servo_DemoState s_demo_state = SERVO_DEMO_HOLD_MIN;
static uint32_t        s_demo_tick  = 0;    /* 当前阶段的起始时刻 */

/* ================= 基本接口 ================= */

void Servo_Init(void)
{
  if (HAL_TIM_PWM_Start(SERVO_TIM_HANDLE, SERVO_TIM_CHANNEL) != HAL_OK)
  {
    Error_Handler();
  }

  /* 上电回到实测的水平点，不是行程中点 */
  Servo_SetPulseUs(SERVO_LEVEL_US);
}

/* 所有设定的唯一出口，安全限幅在此处 */
void Servo_SetPulseUs(uint16_t us)
{
  s_at_limit = 0;

  if (us < SERVO_SAFE_MIN_US)
  {
    us = SERVO_SAFE_MIN_US;
    s_at_limit = 1;
  }
  else if (us > SERVO_SAFE_MAX_US)
  {
    us = SERVO_SAFE_MAX_US;
    s_at_limit = 1;
  }

  s_pulse_us = us;

  s_angle_deg = (float)(us - SERVO_MIN_PULSE_US) / SERVO_US_PER_DEG;

  /* 比较值单位即微秒 */
  __HAL_TIM_SET_COMPARE(SERVO_TIM_HANDLE, SERVO_TIM_CHANNEL, us);
}

void Servo_StepUs(int16_t delta_us)
{
  int32_t us = (int32_t)s_pulse_us + delta_us;

  if (us < 0)
  {
    us = 0;
  }
  else if (us > 0xFFFF)
  {
    us = 0xFFFF;
  }

  Servo_SetPulseUs((uint16_t)us);
}

uint16_t Servo_GetPulseUs(void)
{
  return s_pulse_us;
}

void Servo_SetAngle(float deg)
{
  float us;

  if (deg < 0.0f)
  {
    deg = 0.0f;
  }
  else if (deg > SERVO_MAX_ANGLE_DEG)
  {
    deg = SERVO_MAX_ANGLE_DEG;
  }

  us = (float)SERVO_MIN_PULSE_US + deg * SERVO_US_PER_DEG;

  Servo_SetPulseUs((uint16_t)us);
}

uint8_t Servo_IsAtLimit(void)
{
  return s_at_limit;
}

float Servo_GetAngle(void)
{
  return s_angle_deg;
}

/* ================= 自检演示 ================= */

void Servo_DemoInit(void)
{
  s_demo_state = SERVO_DEMO_HOLD_MIN;
  s_demo_tick  = HAL_GetTick();

  Servo_SetPulseUs(SERVO_SAFE_MIN_US);
}

void Servo_DemoUpdate(void)
{
  uint32_t now     = HAL_GetTick();
  uint32_t elapsed = now - s_demo_tick;

  float swept = SERVO_DEMO_SPEED_UPS * (float)elapsed / 1000.0f;

  switch (s_demo_state)
  {
    case SERVO_DEMO_HOLD_MIN:
      if (elapsed >= SERVO_DEMO_HOLD_MS)
      {
        s_demo_state = SERVO_DEMO_SWEEP_UP;
        s_demo_tick  = now;
      }
      break;

    case SERVO_DEMO_SWEEP_UP:
      if (((float)SERVO_SAFE_MIN_US + swept) >= (float)SERVO_SAFE_MAX_US)
      {
        Servo_SetPulseUs(SERVO_SAFE_MAX_US);
        s_demo_state = SERVO_DEMO_HOLD_MAX;
        s_demo_tick  = now;
      }
      else
      {
        Servo_SetPulseUs((uint16_t)((float)SERVO_SAFE_MIN_US + swept));
      }
      break;

    case SERVO_DEMO_HOLD_MAX:
      if (elapsed >= SERVO_DEMO_HOLD_MS)
      {
        s_demo_state = SERVO_DEMO_SWEEP_DOWN;
        s_demo_tick  = now;
      }
      break;

    default:    /* SERVO_DEMO_SWEEP_DOWN */
      if (((float)SERVO_SAFE_MAX_US - swept) <= (float)SERVO_SAFE_MIN_US)
      {
        Servo_SetPulseUs(SERVO_SAFE_MIN_US);
        s_demo_state = SERVO_DEMO_HOLD_MIN;
        s_demo_tick  = now;
      }
      else
      {
        Servo_SetPulseUs((uint16_t)((float)SERVO_SAFE_MAX_US - swept));
      }
      break;
  }
}

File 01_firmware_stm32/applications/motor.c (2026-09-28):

/**
  ******************************************************************************
  * @file           : motor.c
  * @brief          : TB6612FNG 双路电机驱动 —— TIM8_CH1/CH2 调速 + GPIO 方向
  ******************************************************************************
  * @note  TIM8 与 PC6/PC7 的复用由 CubeMX 生成的 MX_TIM8_Init() 完成，
  *        PF0~PF4 由 MX_GPIO_Init() 配置，本文件只负责启动 PWM 与业务逻辑。
  *        因此 Motor_Init() 必须在这两个 MX 初始化之后调用。
  ******************************************************************************
  */

#include "motor.h"
#include "tim.h"

/* ---------------- 引脚定义 ---------------- */
#define MOTOR_PWM_HANDLE        (&htim8)
#define MOTOR_PWMA_CHANNEL      TIM_CHANNEL_1   /* PC6 */
#define MOTOR_PWMB_CHANNEL      TIM_CHANNEL_2   /* PC7 */

#define MOTOR_DIR_GPIO_PORT     GPIOF
#define MOTOR_AIN1_PIN          GPIO_PIN_0
#define MOTOR_AIN2_PIN          GPIO_PIN_1
#define MOTOR_BIN1_PIN          GPIO_PIN_2
#define MOTOR_BIN2_PIN          GPIO_PIN_3

#define MOTOR_STBY_GPIO_PORT    GPIOF
#define MOTOR_STBY_PIN          GPIO_PIN_4

/* ---------------- 每路电机的静态配置 ---------------- */
typedef struct
{
  GPIO_TypeDef *dir_port;
  uint16_t      in1_pin;
  uint16_t      in2_pin;
  uint32_t      channel;       /* TIM8 的 PWM 通道 */
  uint8_t       reversed;      /* 安装方向修正 */
} Motor_Config;

static const Motor_Config s_motor_cfg[MOTOR_NUM] =
{
  [MOTOR_LEFT] = {
    .dir_port = MOTOR_DIR_GPIO_PORT,
    .in1_pin  = MOTOR_AIN1_PIN,
    .in2_pin  = MOTOR_AIN2_PIN,
    .channel  = MOTOR_PWMA_CHANNEL,
    .reversed = MOTOR_LEFT_REVERSED,
  },
  [MOTOR_RIGHT] = {
    .dir_port = MOTOR_DIR_GPIO_PORT,
    .in1_pin  = MOTOR_BIN1_PIN,
    .in2_pin  = MOTOR_BIN2_PIN,
    .channel  = MOTOR_PWMB_CHANNEL,
    .reversed = MOTOR_RIGHT_REVERSED,
  },
};

/* ---------------- 运行时状态 ---------------- */
static uint32_t       s_period      = 0;                  /* ARR + 1，即满占空比计数 */
static int16_t        s_speed[MOTOR_NUM] = {0, 0};        /* 当前设定速度 */
static Motor_StopMode s_stop_mode   = MOTOR_STOP_COAST;
static uint8_t        s_initialized = 0;

/* ---------------- 内部函数 ---------------- */

/**
  * @brief  按方向标志驱动 IN1 / IN2
  */
static void Motor_ApplyDirection(const Motor_Config *cfg, uint8_t in1, uint8_t in2)
{
  HAL_GPIO_WritePin(cfg->dir_port, cfg->in1_pin, in1 ? GPIO_PIN_SET : GPIO_PIN_RESET);
  HAL_GPIO_WritePin(cfg->dir_port, cfg->in2_pin, in2 ? GPIO_PIN_SET : GPIO_PIN_RESET);
}

/**
  * @brief  把限幅后的速度落到硬件上
  */
static void Motor_Apply(Motor_ID id, int16_t speed)
{
  const Motor_Config *cfg = &s_motor_cfg[id];
  int32_t             mag = (speed >= 0) ? speed : -speed;
  uint8_t             forward;

  if (speed == 0)
  {
    __HAL_TIM_SET_COMPARE(MOTOR_PWM_HANDLE, cfg->channel, 0);
    Motor_ApplyDirection(cfg, (s_stop_mode == MOTOR_STOP_BRAKE),
                              (s_stop_mode == MOTOR_STOP_BRAKE));
    return;
  }

  forward = (speed > 0);
  if (cfg->reversed)
  {
    forward = !forward;
  }
  Motor_ApplyDirection(cfg, forward, !forward);

  /* 速度量程 -> 占空比，用 32 位中间量避免溢出 */
  __HAL_TIM_SET_COMPARE(MOTOR_PWM_HANDLE, cfg->channel,
                        (uint32_t)((mag * (int32_t)s_period) / MOTOR_SPEED_MAX));
}

/* ---------------- 对外接口 ---------------- */

void Motor_Init(void)
{
  /* 方向脚与 STBY 先全部拉低，保证启动 PWM 前电机不会误动作 */
  HAL_GPIO_WritePin(MOTOR_DIR_GPIO_PORT,
                    MOTOR_AIN1_PIN | MOTOR_AIN2_PIN | MOTOR_BIN1_PIN | MOTOR_BIN2_PIN,
                    GPIO_PIN_RESET);
  HAL_GPIO_WritePin(MOTOR_STBY_GPIO_PORT, MOTOR_STBY_PIN, GPIO_PIN_RESET);

  /* 满占空比计数取自 CubeMX 里设定的 ARR，改动 TIM8 Period 不用同步改这里 */
  s_period = __HAL_TIM_GET_AUTORELOAD(MOTOR_PWM_HANDLE) + 1U;

  __HAL_TIM_SET_COMPARE(MOTOR_PWM_HANDLE, MOTOR_PWMA_CHANNEL, 0);
  __HAL_TIM_SET_COMPARE(MOTOR_PWM_HANDLE, MOTOR_PWMB_CHANNEL, 0);

  if (HAL_TIM_PWM_Start(MOTOR_PWM_HANDLE, MOTOR_PWMA_CHANNEL) != HAL_OK)
  {
    Error_Handler();
  }
  if (HAL_TIM_PWM_Start(MOTOR_PWM_HANDLE, MOTOR_PWMB_CHANNEL) != HAL_OK)
  {
    Error_Handler();
  }

  s_speed[MOTOR_LEFT]  = 0;
  s_speed[MOTOR_RIGHT] = 0;
  s_stop_mode          = MOTOR_STOP_COAST;
  s_initialized        = 1;

  Motor_Apply(MOTOR_LEFT,  0);
  Motor_Apply(MOTOR_RIGHT, 0);
}

void Motor_Enable(void)
{
  HAL_GPIO_WritePin(MOTOR_STBY_GPIO_PORT, MOTOR_STBY_PIN, GPIO_PIN_SET);
}

void Motor_Disable(void)
{
  HAL_GPIO_WritePin(MOTOR_STBY_GPIO_PORT, MOTOR_STBY_PIN, GPIO_PIN_RESET);
}

void Motor_SetSpeed(Motor_ID id, int16_t speed)
{
  if ((id >= MOTOR_NUM) || (s_initialized == 0))
  {
    return;
  }

  if (speed > MOTOR_SPEED_MAX)
  {
    speed = MOTOR_SPEED_MAX;
  }
  else if (speed < -MOTOR_SPEED_MAX)
  {
    speed = -MOTOR_SPEED_MAX;
  }

  s_speed[id] = speed;
  Motor_Apply(id, speed);
}

void Motor_SetSpeeds(int16_t left, int16_t right)
{
  Motor_SetSpeed(MOTOR_LEFT,  left);
  Motor_SetSpeed(MOTOR_RIGHT, right);
}

int16_t Motor_GetSpeed(Motor_ID id)
{
  return (id < MOTOR_NUM) ? s_speed[id] : 0;
}

void Motor_SetStopMode(Motor_StopMode mode)
{
  s_stop_mode = mode;

  /* 已经停着的电机立刻切到新的停车方式 */
  for (uint8_t i = 0; i < MOTOR_NUM; i++)
  {
    if (s_speed[i] == 0)
    {
      Motor_Apply((Motor_ID)i, 0);
    }
  }
}

void Motor_Brake(Motor_ID id)
{
  if ((id >= MOTOR_NUM) || (s_initialized == 0))
  {
    return;
  }

  s_speed[id] = 0;
  __HAL_TIM_SET_COMPARE(MOTOR_PWM_HANDLE, s_motor_cfg[id].channel, 0);
  Motor_ApplyDirection(&s_motor_cfg[id], 1, 1);
}

void Motor_Coast(Motor_ID id)
{
  if ((id >= MOTOR_NUM) || (s_initialized == 0))
  {
    return;
  }

  s_speed[id] = 0;
  __HAL_TIM_SET_COMPARE(MOTOR_PWM_HANDLE, s_motor_cfg[id].channel, 0);
  Motor_ApplyDirection(&s_motor_cfg[id], 0, 0);
}

void Motor_BrakeAll(void)
{
  Motor_Brake(MOTOR_LEFT);
  Motor_Brake(MOTOR_RIGHT);
}

void Motor_CoastAll(void)
{
  Motor_Coast(MOTOR_LEFT);
  Motor_Coast(MOTOR_RIGHT);
}

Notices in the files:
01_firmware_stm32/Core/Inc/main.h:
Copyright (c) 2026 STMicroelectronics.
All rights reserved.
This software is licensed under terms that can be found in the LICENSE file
